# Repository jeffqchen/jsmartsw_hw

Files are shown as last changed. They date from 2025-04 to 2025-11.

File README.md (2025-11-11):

# jsmartsw_hw

This is the hardware repository of the jSmartSW project.

The hardware is consisted of two parts. The jSmartSW mainboard contains the main I/O and logic board. The keypad contains visual feedback interfaces and tactile inputs.

Detailed building guides and technical details are documented in the project wiki pages.

For functionality and day-to-day usage, please refer to the [main project repository](https://github.com/jeffqchen/jSmartSW)

## Primary Parts

### Main Board

The main board interfaces with and utilizes a Raspberry Pi Pico to run the logic programs of this project. The main board is needed for the project.

The main board has many ports for power and I/O:
- **Power**
  - **DC 5V barrel jack** (optional)

    The preferred source to power jSmartSW.
    
  - **USB-C jack** (optional)
 
    USB functionality is provided via this port. You can also power the jSmartSW from this port.

  - **Toggle switch** (optional)
    
    For turning the power from the barrel jack and USB-C jack on or off.

- **Video & Audio**
  - **HD15 video/audio passthrough input** (optional, recommended):
    
    Since the project communicates to the RetroTink 4K primarily via the HD15 port, you can connect HD15 sources to this port and feed it to the RetroTink 4K.
    
  - **HD15 video passthrough output** (optional):
    
    The video input from the passthrough input port is output from this port. The serial control commands are sent from this port to the RetroTink 4K if a USB-C connection is not present to the RetroTink 4K.
    
  - **3.5mm TRS barrel jack**:
    
    Audio signal input from the passthrough input pin 12 & 15 is broken out to this port, so you can use a 3.5mm TRS audio cable and feed it to the RetroTink 4K.

- **Communication**
  - **2x4 right-angle pin header**:
  
    Communicates with the gSCARTsw.
    
  - **2x7 right-angle pin header** (optional):

    Communicates with the optional keypad.
    
  - **HD15 video passthrough output** (already listed):

    The serial control commands are sent from this port to the RetroTink 4K if a USB-C connection is not present to the RetroTink 4K.
    
  - **USB-C jack** (already listed):

    When connected to the RetroTink 4K, it will become the preferred channel of communication. It also supplies power into the RetroTink 4K. In this case, the 5V barreljack must be populated as the main source of power.

### Keypad

The keypad is the primary user interface of jSmartSW. It has a screen, addressable RGB LEDs, and 8 key switches.

- Screen

  A 0.91 inch OLED SSD1306 screen at 128x32 resolution.

- 16 (8x2) WS2812b OR WS2812b 2020 addressable RGB LEDs.

  An array of addressabvle RGB LEDs for indicating device running state and prodiving visual assistance.
  
- 8x Cherry MX keyboard switches with XDA key caps

  An array of keyboard switches for controlling functionalities of jSmartSW.

- Keypad Faceplate Panel

  Cosmetic face panel with markings. Markings will be illuminated by the RGB LEDs.

- 3D printed Keypad body shell & light shroud

------
Shield: [][cc-by-sa]

This work is licensed under a
[Creative Commons Attribution-ShareAlike 4.0 International License][cc-by-sa].

[][cc-by-sa]

[cc-by-sa]: http://creativecommons.org/licenses/by-sa/4.0/
[cc-by-sa-image]: https://licensebuttons.net/l/by-sa/4.0/88x31.png
[cc-by-sa-shield]: https://img.shields.io/badge/License-CC%20BY--SA%204.0-lightgrey.svg

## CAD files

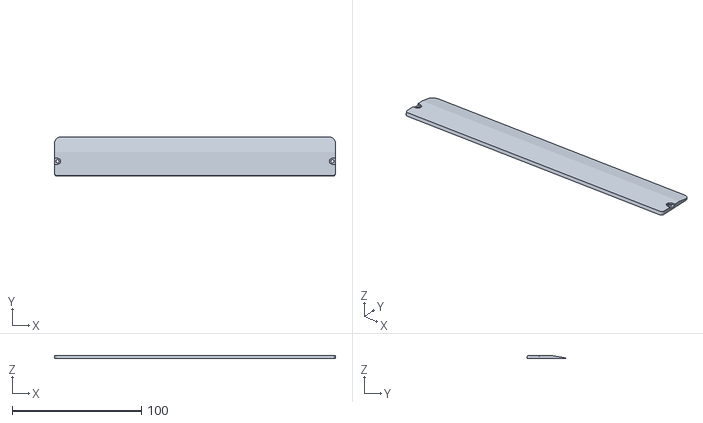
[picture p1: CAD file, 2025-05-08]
3D Print/Keypad Bottom Plate.stl
217.2 x 30.4 x 2.50

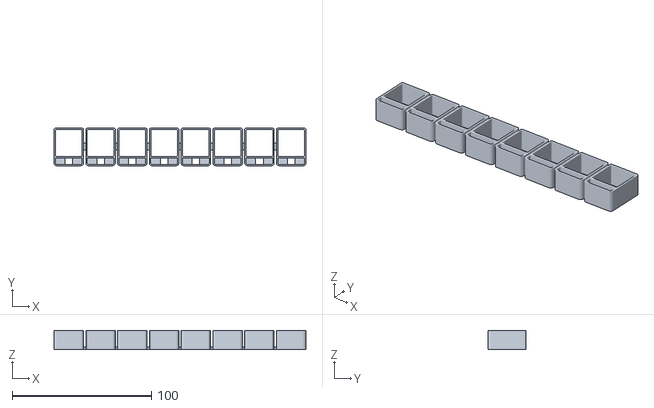
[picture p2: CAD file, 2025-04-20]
3D Print/LED Light Pipe.stl
181.2 x 27.0 x 13.8

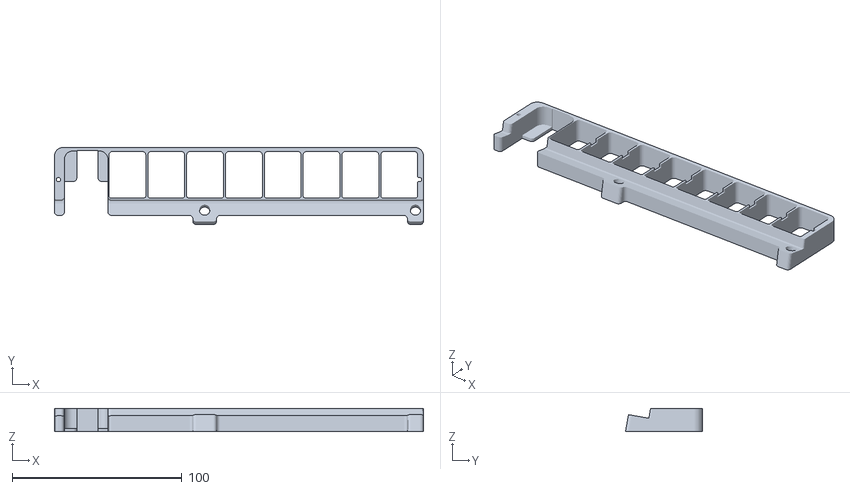
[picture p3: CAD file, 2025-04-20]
3D Print/Keypad Body.stl
217.2 x 45.4 x 13.8

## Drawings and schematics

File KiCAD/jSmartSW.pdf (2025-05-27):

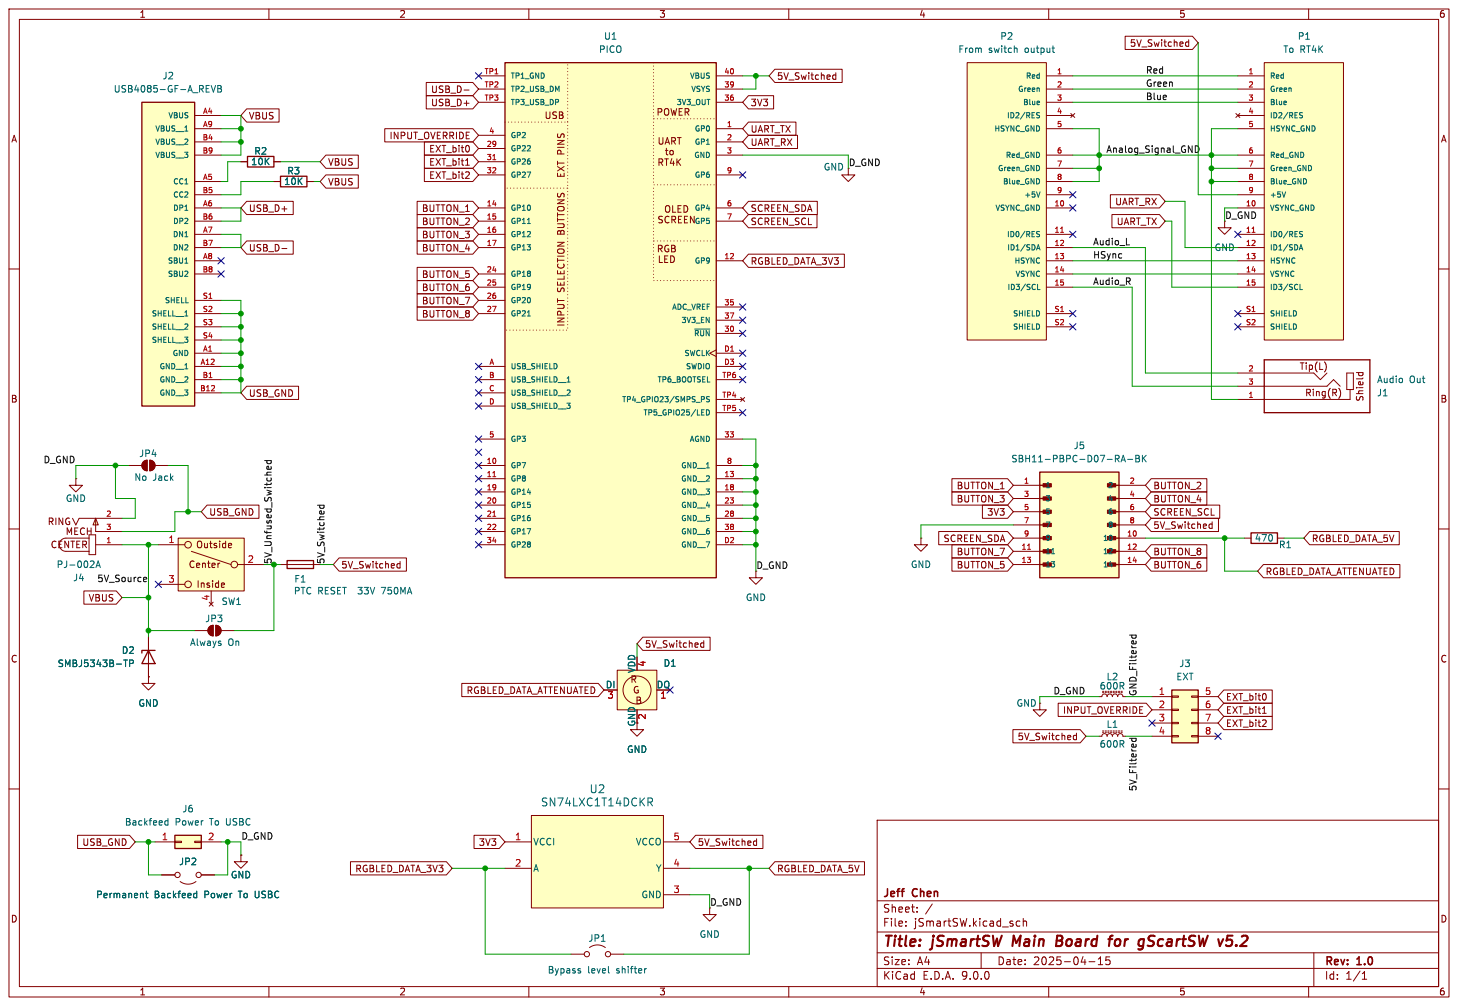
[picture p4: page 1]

J6 Backfeed Power To USBC

File: jSmartSW.kicad_sch Sheet: / Jeff Chen

Id: 1/1 Title: jSmartSW Main Board for gScartSW v5.2

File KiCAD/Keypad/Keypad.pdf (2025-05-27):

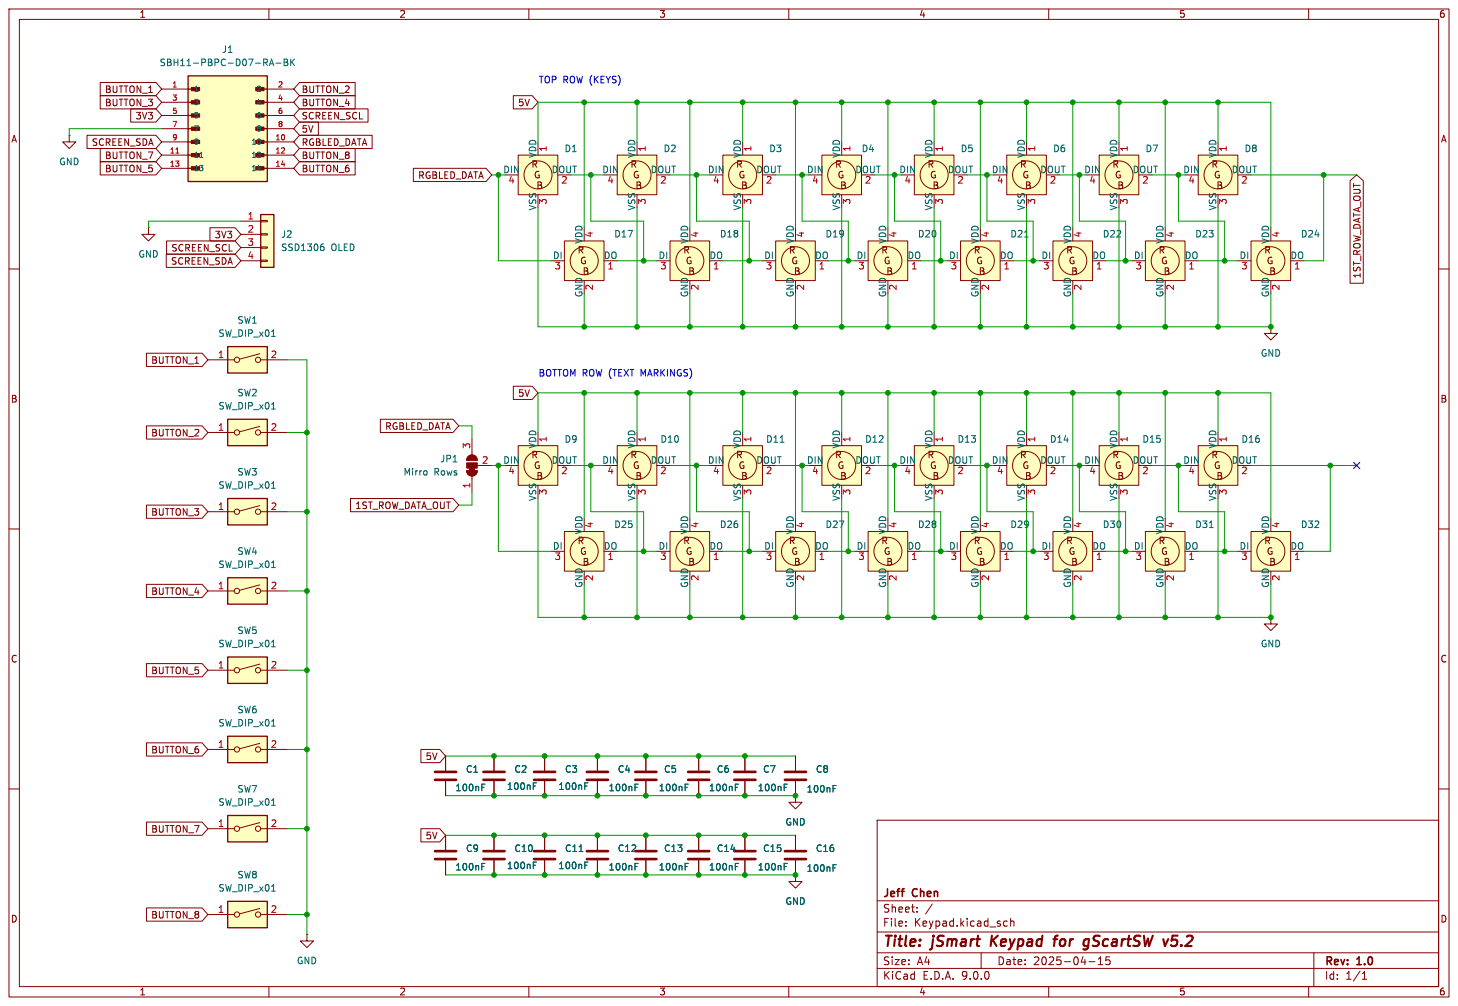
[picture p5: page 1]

File: Keypad.kicad_sch Sheet: / Jeff Chen

Id: 1/1 Title: jSmart Keypad for gScartSW v5.2

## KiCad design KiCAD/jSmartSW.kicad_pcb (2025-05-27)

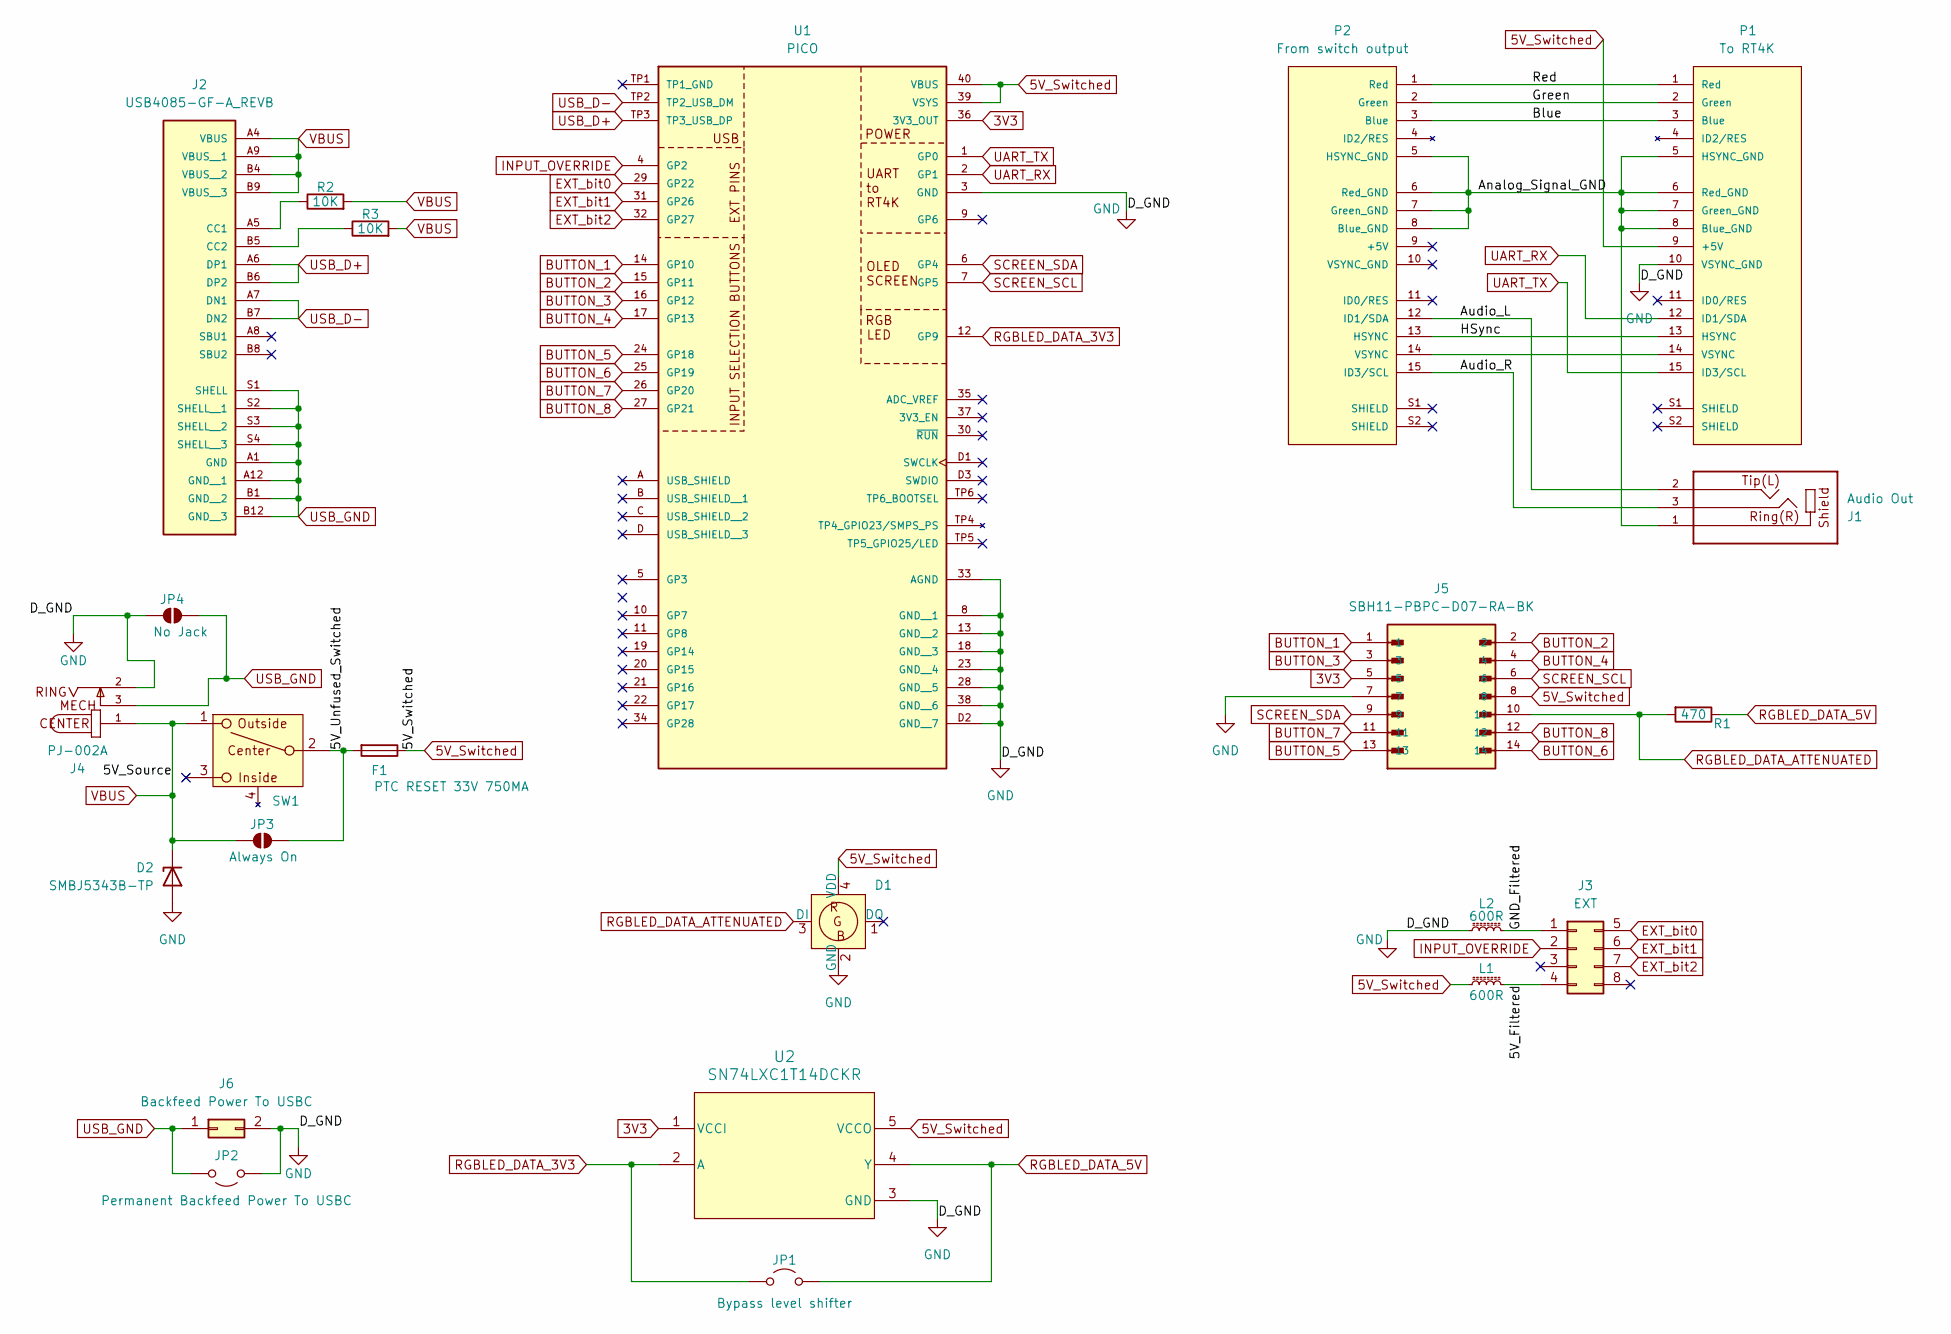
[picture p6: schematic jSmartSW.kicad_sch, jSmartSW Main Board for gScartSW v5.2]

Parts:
D1: WS2812b_2020
D2: SMBJ5343B-TP; D_SMB
F1: PTC RESET 33V 750MA; Fuse_1812_4532Metric_Pad1.30x3.40mm_HandSolder
J1: Audio Out; 3.5mm_jack_horizontal; PARTREV 1.02
J2: USB4085-GF-A_REVB; GCT_USB4085-GF-A_REVB; PARTREV B
J3: EXT; PinHeader_2x04_P2.54mm_Horizontal
J4: PJ-002A; CUI_PJ-002A
J5: SBH11-PBPC-D07-RA-BK; SULLINS_SBH11-PBPC-D07-RA-BK; PARTREV J
J6: Backfeed Power To USBC; PinHeader_1x02_P2.54mm_Horizontal
JP1: Bypass level shifter; SolderJumper-2_P1.3mm_Open_RoundedPad1.0x1.5mm
JP2: Permanent Backfeed Power To USBC; SolderJumper-2_P1.3mm_Bridged2Bar_RoundedPad1.0x1.5mm
JP3: Always On; SolderJumper-2_P1.3mm_Open_RoundedPad1.0x1.5mm
JP4: No Jack; SolderJumper-2_P1.3mm_Open_RoundedPad1.0x1.5mm
L1, L2: 600R; L_1206_3216Metric_Pad1.22x1.90mm_HandSolder
P1: To RT4K; VGA_female_rightangle_slim; PARTREV N/A
P2: From switch output; VGA_male_rightangle_slim; PARTREV N/A
R1: 470; R_0805_2012Metric_Pad1.20x1.40mm_HandSolder
R2, R3: 10K; R_0603_1608Metric_Pad0.98x0.95mm_HandSolder
SW1: BST13T1AVR
U1: PICO; RP2040_PICO; PARTREV 1.9
U2: SN74LXC1T14DCKR; DCK0005A-IPC_A

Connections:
3V3: J5.5, U1.36 (3V3_OUT), U2.1 (VCCI)
5V_Switched: D1.4 (VDD), F1.1, J5.8, L1.1, P1.9 (+5V), U1.39 (VSYS), U1.40 (VBUS), U2.5 (VCCO)
/5V_Filtered: J3.4, L1.2
/5V_Unfused_Switched: F1.2, JP3.1 (A), SW1.2 (Center)
/Analog_Signal_GND: J1.1, P1.5 (HSYNC_GND), P1.6 (Red_GND), P1.7 (Green_GND), P1.8 (Blue_GND), P2.5 (HSYNC_GND), P2.6 (Red_GND), P2.7 (Green_GND), P2.8 (Blue_GND)
/Audio_L: J1.2, P2.12 (ID1/SDA)
/Audio_R: J1.3, P2.15 (ID3/SCL)
/Blue: P1.3 (Blue), P2.3 (Blue)
/GND_Filtered: J3.1, L2.2
/Green: P1.2 (Green), P2.2 (Green)
/HSync: P1.13 (HSYNC), P2.13 (HSYNC)
/Red: P1.1 (Red), P2.1 (Red)
BUTTON_1: J5.1, U1.14 (GP10)
BUTTON_2: J5.2, U1.15 (GP11)
BUTTON_3: J5.3, U1.16 (GP12)
BUTTON_4: J5.4, U1.17 (GP13)
BUTTON_5: J5.13, U1.24 (GP18)
BUTTON_6: J5.14, U1.25 (GP19)
BUTTON_7: J5.11, U1.26 (GP20)
BUTTON_8: J5.12, U1.27 (GP21)
EXT_bit0: J3.5, U1.29 (GP22)
EXT_bit1: J3.6, U1.31 (GP26)
EXT_bit2: J3.7, U1.32 (GP27)
GND: D1.2 (GND), D2.2 (A), J4.2, J5.7, J6.2, JP2.1 (A), JP4.2 (B), L2.1, P1.10 (VSYNC_GND), U1.3 (GND), U1.8 (GND__1), U1.13 (GND__2), U1.18 (GND__3), U1.23 (GND__4), U1.28 (GND__5), U1.33 (AGND), U1.38 (GND__6), U1.D2 (GND__7), U2.3 (GND)
INPUT_OVERRIDE: J3.2, U1.4 (GP2)
unnamed: J2.A5 (CC1), R2.1
unnamed: J2.B5 (CC2), R3.1
unnamed: P1.14 (VSYNC), P2.14 (VSYNC)
RGBLED_DATA_3V3: JP1.1 (A), U1.12 (GP9), U2.2 (A)
RGBLED_DATA_5V: JP1.2 (B), R1.1, U2.4 (Y)
RGBLED_DATA_ATTENUATED: D1.3 (DI), J5.10, R1.2
SCREEN_SCL: J5.6, U1.7 (GP5)
SCREEN_SDA: J5.9, U1.6 (GP4)
UART_RX: P1.12 (ID1/SDA), U1.2 (GP1)
UART_TX: P1.15 (ID3/SCL), U1.1 (GP0)
USB_D+: J2.A6 (DP1), J2.B6 (DP2), U1.TP3 (TP3_USB_DP)
USB_D-: J2.A7 (DN1), J2.B7 (DN2), U1.TP2 (TP2_USB_DM)
USB_GND: J2.A1 (GND), J2.A12 (GND__1), J2.B1 (GND__2), J2.B12 (GND__3), J2.S1 (SHELL), J2.S2 (SHELL__1), J2.S3 (SHELL__2), J2.S4 (SHELL__3), J4.3, J6.1, JP2.2 (B), JP4.1 (A)
VBUS: D2.1 (K), J2.A4 (VBUS), J2.A9 (VBUS__1), J2.B4 (VBUS__2), J2.B9 (VBUS__3), J4.1, JP3.2 (B), R2.2, R3.2, SW1.1 (Outside)

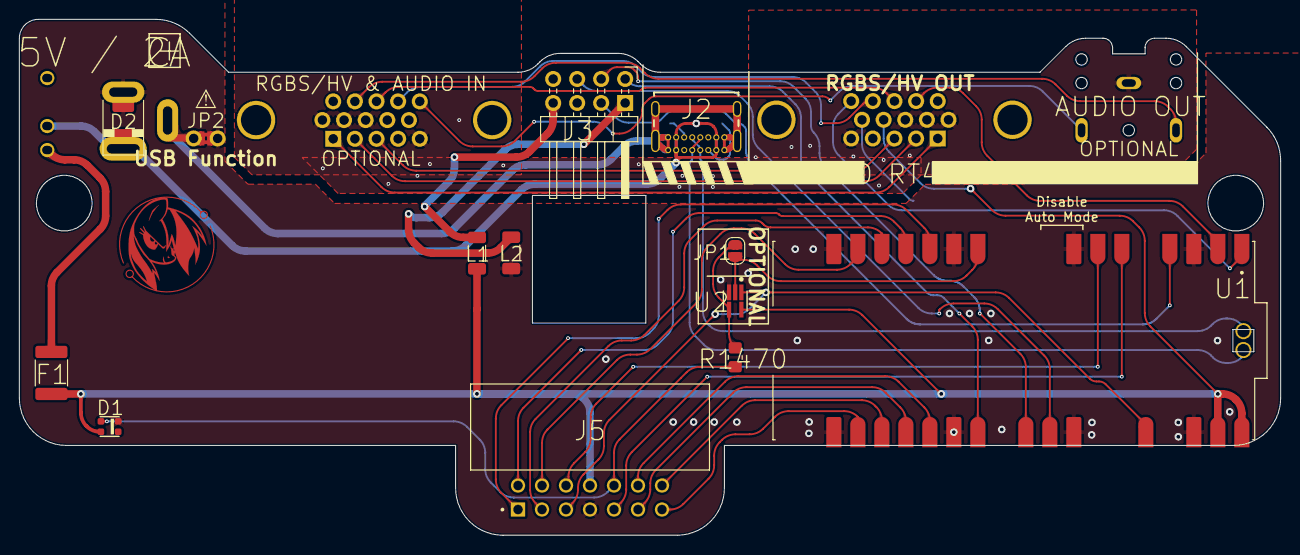
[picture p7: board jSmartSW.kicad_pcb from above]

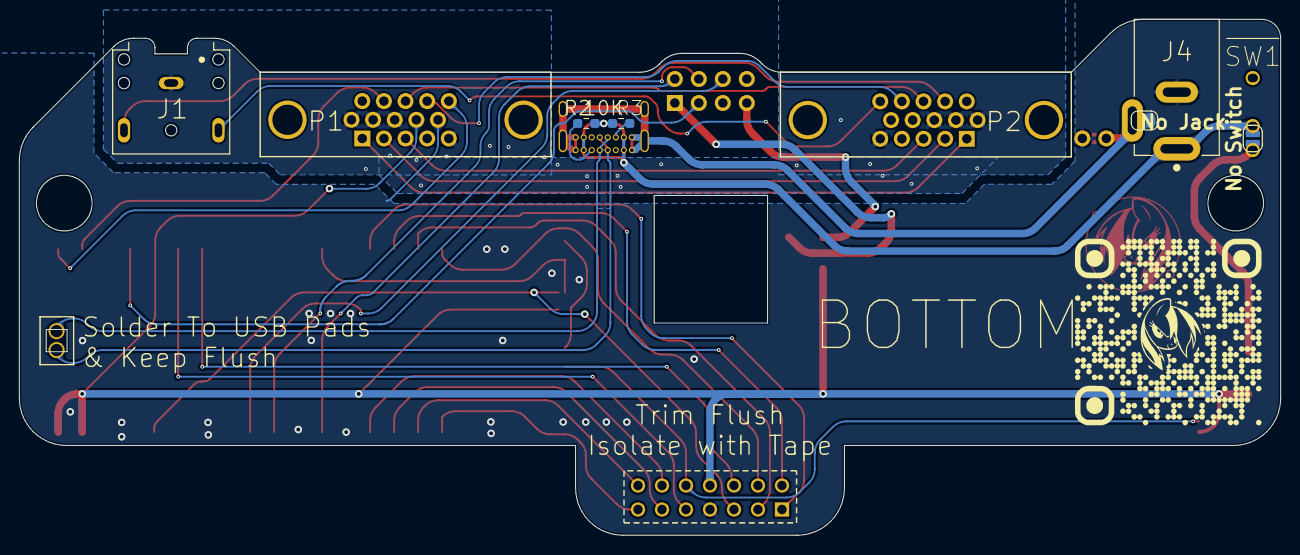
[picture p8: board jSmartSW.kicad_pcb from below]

Board: 2 copper layers, 133.5 x 54.6 mm, 23 parts (9 on the bottom side), 39 nets.

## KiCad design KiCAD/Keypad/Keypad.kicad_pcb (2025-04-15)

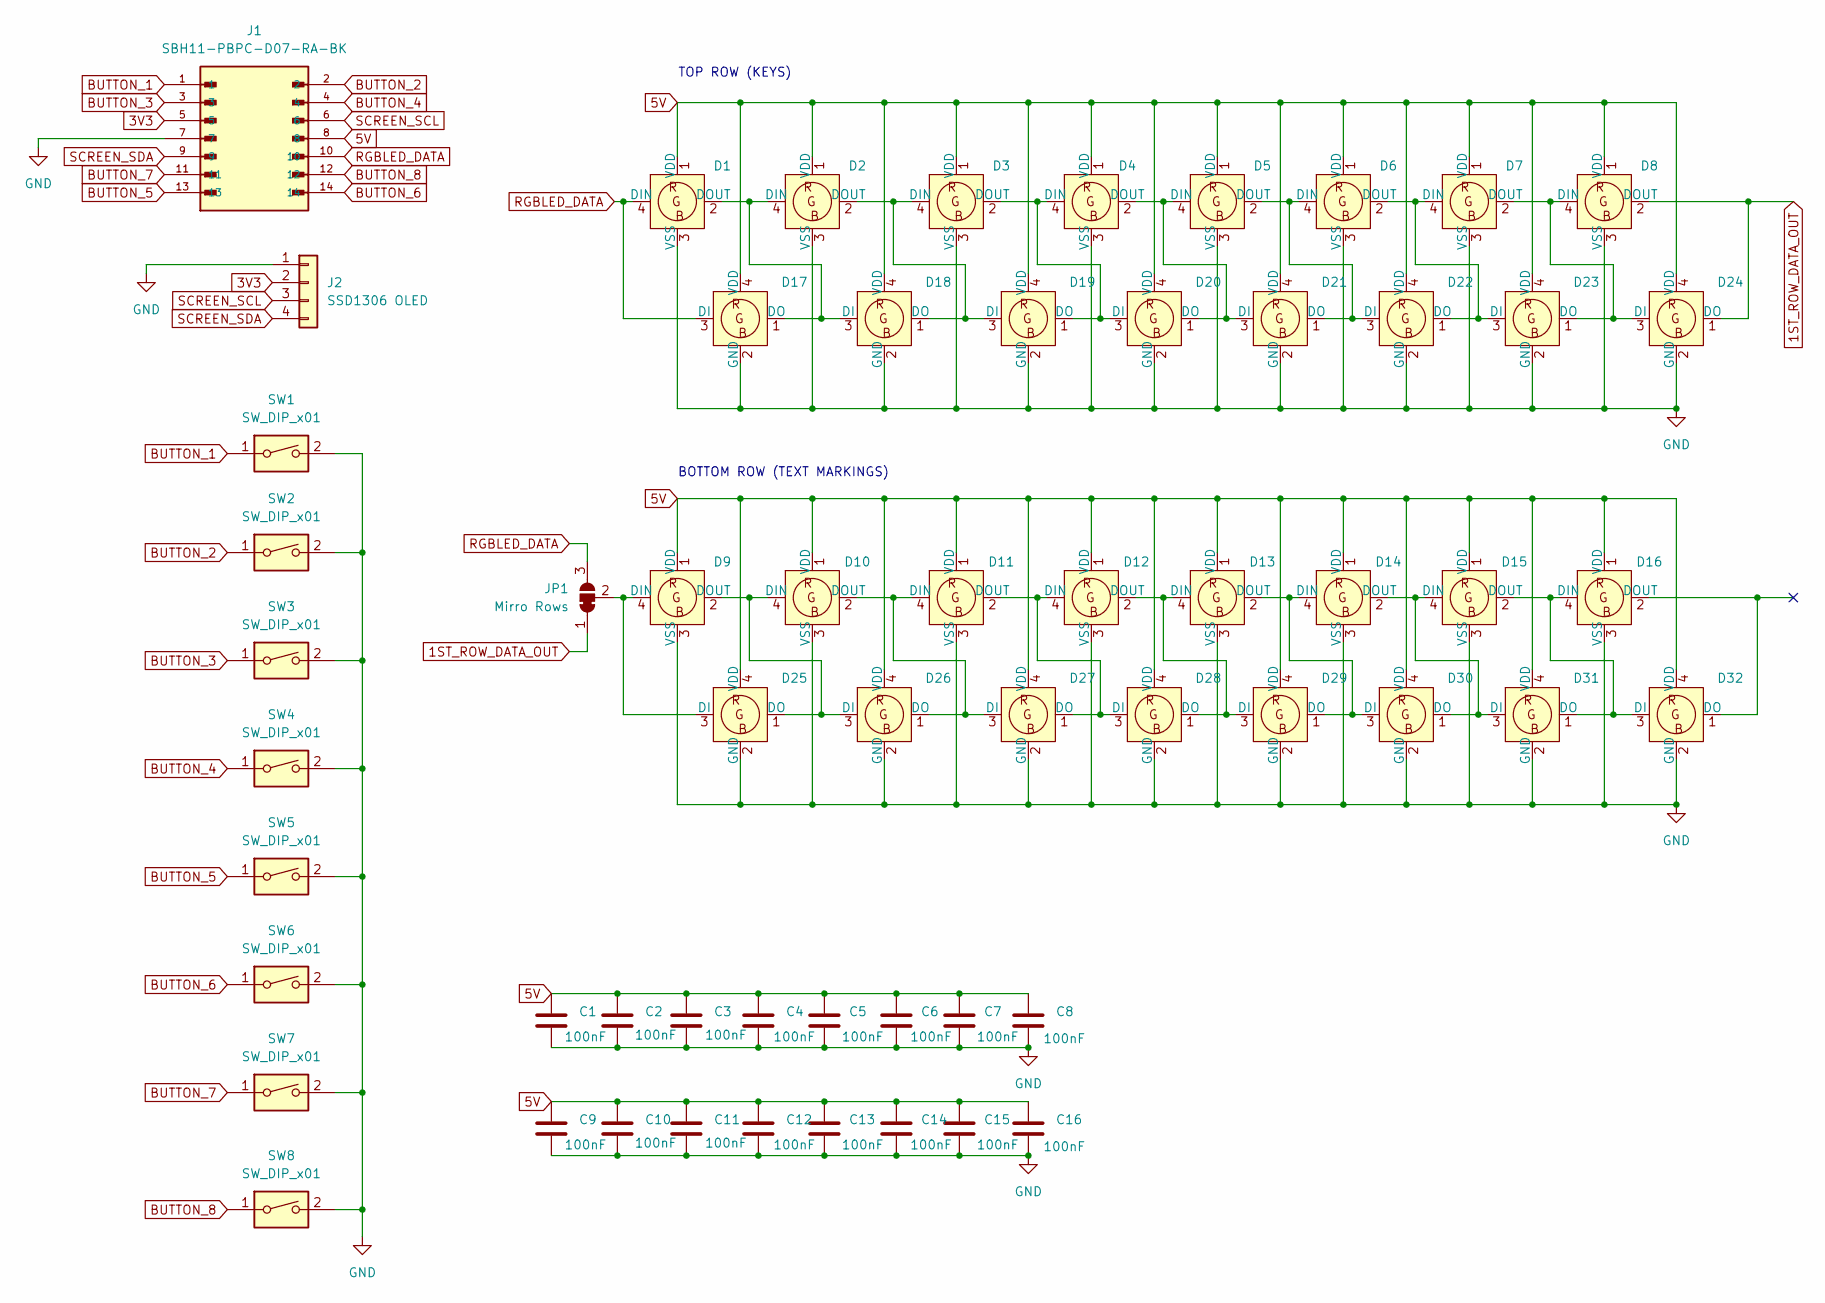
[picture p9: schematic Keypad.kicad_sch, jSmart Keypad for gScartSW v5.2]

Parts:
C1, C2, C3, C4, C5, C6, C7, C8, C9, C10, C11, C12, C13, C14, C15, C16: 100nF; R_0603_1608Metric_Pad0.98x0.95mm_HandSolder
D1, D2, D3, D4, D5, D6, D7, D8, D9, D10, D11, D12, D13, D14, D15, D16: WS2812B LED
D17, D18, D19, D20, D21, D22, D23, D24, D25, D26, D27, D28, D29, D30, D31, D32: WS2812b_2020
J1: SBH11-PBPC-D07-RA-BK; SULLINS_SBH11-PBPC-D07-RA-BK; PARTREV J
J2: SSD1306 OLED; PinHeader_1x04_P2.54mm_Vertical
JP1: Mirro Rows; SolderJumper-3_P1.3mm_Bridged2Bar12_RoundedPad1.0x1.5mm
SW1, SW2, SW3, SW4, SW5, SW6, SW7, SW8: SW_DIP_x01; SW_Cherry_MX_1.00u_Plate

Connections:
1ST_ROW_DATA_OUT: D8.2 (DOUT), D24.1 (DO), JP1.1 (A)
3V3: J1.5, J2.2
5V: C1.1, C2.1, C3.1, C4.1, C5.1, C6.1, C7.1, C8.1, C9.1, C10.1, C11.1, C12.1, C13.1, C14.1, C15.1, C16.1, D1.1 (VDD), D2.1 (VDD), D3.1 (VDD), D4.1 (VDD), D5.1 (VDD), D6.1 (VDD), D7.1 (VDD), D8.1 (VDD), D9.1 (VDD), D10.1 (VDD), D11.1 (VDD), D12.1 (VDD), D13.1 (VDD), D14.1 (VDD), D15.1 (VDD), D16.1 (VDD), D17.4 (VDD), D18.4 (VDD), D19.4 (VDD), D20.4 (VDD), D21.4 (VDD), D22.4 (VDD), D23.4 (VDD), D24.4 (VDD), D25.4 (VDD), D26.4 (VDD), D27.4 (VDD), D28.4 (VDD), D29.4 (VDD), D30.4 (VDD), D31.4 (VDD), D32.4 (VDD), J1.8
BUTTON_1: J1.1, SW1.1
BUTTON_2: J1.2, SW2.1
BUTTON_3: J1.3, SW3.1
BUTTON_4: J1.4, SW4.1
BUTTON_5: J1.13, SW5.1
BUTTON_6: J1.14, SW6.1
BUTTON_7: J1.11, SW7.1
BUTTON_8: J1.12, SW8.1
GND: C1.2, C2.2, C3.2, C4.2, C5.2, C6.2, C7.2, C8.2, C9.2, C10.2, C11.2, C12.2, C13.2, C14.2, C15.2, C16.2, D1.3 (VSS), D2.3 (VSS), D3.3 (VSS), D4.3 (VSS), D5.3 (VSS), D6.3 (VSS), D7.3 (VSS), D8.3 (VSS), D9.3 (VSS), D10.3 (VSS), D11.3 (VSS), D12.3 (VSS), D13.3 (VSS), D14.3 (VSS), D15.3 (VSS), D16.3 (VSS), D17.2 (GND), D18.2 (GND), D19.2 (GND), D20.2 (GND), D21.2 (GND), D22.2 (GND), D23.2 (GND), D24.2 (GND), D25.2 (GND), D26.2 (GND), D27.2 (GND), D28.2 (GND), D29.2 (GND), D30.2 (GND), D31.2 (GND), D32.2 (GND), J1.7, J2.1, SW1.2, SW2.2, SW3.2, SW4.2, SW5.2, SW6.2, SW7.2, SW8.2
unnamed: D1.2 (DOUT), D2.4 (DIN), D17.1 (DO), D18.3 (DI)
unnamed: D9.2 (DOUT), D10.4 (DIN), D25.1 (DO), D26.3 (DI)
unnamed: D10.2 (DOUT), D11.4 (DIN), D26.1 (DO), D27.3 (DI)
unnamed: D11.2 (DOUT), D12.4 (DIN), D27.1 (DO), D28.3 (DI)
unnamed: D12.2 (DOUT), D13.4 (DIN), D28.1 (DO), D29.3 (DI)
unnamed: D13.2 (DOUT), D14.4 (DIN), D29.1 (DO), D30.3 (DI)
unnamed: D14.2 (DOUT), D15.4 (DIN), D30.1 (DO), D31.3 (DI)
unnamed: D15.2 (DOUT), D16.4 (DIN), D31.1 (DO), D32.3 (DI)
unnamed: D2.2 (DOUT), D3.4 (DIN), D18.1 (DO), D19.3 (DI)
unnamed: D3.2 (DOUT), D4.4 (DIN), D19.1 (DO), D20.3 (DI)
unnamed: D4.2 (DOUT), D5.4 (DIN), D20.1 (DO), D21.3 (DI)
unnamed: D5.2 (DOUT), D6.4 (DIN), D21.1 (DO), D22.3 (DI)
unnamed: D6.2 (DOUT), D7.4 (DIN), D22.1 (DO), D23.3 (DI)
unnamed: D7.2 (DOUT), D8.4 (DIN), D23.1 (DO), D24.3 (DI)
unnamed: D9.4 (DIN), D25.3 (DI), JP1.2 (C)
RGBLED_DATA: D1.4 (DIN), D17.3 (DI), J1.10, JP1.3 (B)
SCREEN_SCL: J1.6, J2.3
SCREEN_SDA: J1.9, J2.4

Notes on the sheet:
TOP ROW (KEYS)
BOTTOM ROW (TEXT MARKINGS)

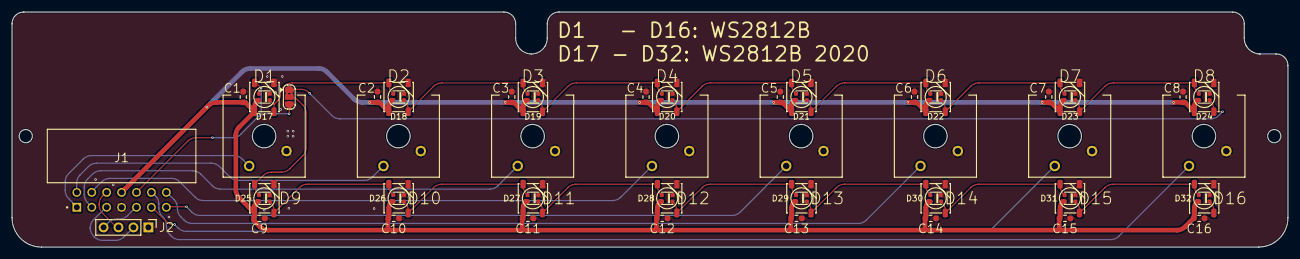
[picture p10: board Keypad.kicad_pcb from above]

Board: 2 copper layers, 217.2 x 40.0 mm, 59 parts (0 on the bottom side), 30 nets.

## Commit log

2025-04-15 Initial Version
    [Keypad Panel-B_Cu.gbr, Keypad Panel-B_Mask.gbr, Keypad Panel-B_Paste.gbr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]
2025-04-20 3D Print STL files
    [Keypad Body.stl, Keypad Bottom Plate.stl, LED Light Pipe.stl]
2025-05-08 Update Keypad Bottom Plate.stl
    Improve model fitness
    [Keypad Bottom Plate.stl]
2025-05-27 Update Main PCB Silkscreen
    [jSmartSW-B_Cu.gbr, jSmartSW-B_Mask.gbr, jSmartSW-B_Paste.gbr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]

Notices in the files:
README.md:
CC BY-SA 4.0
